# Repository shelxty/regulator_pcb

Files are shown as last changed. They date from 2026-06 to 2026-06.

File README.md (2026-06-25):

# 5V to 3.3V TPS79333 Regulator Board



After a lot of struggle with attempting to understand KiCad (thank you Hack Club Fallout mentors!) I made a simple linear voltage regulator to get started with learning, since this was a project simple enough to actually understand completely (schematic, PCB, everything). It's the first PCB I fully finished, designed in KiCad. I guess it can also be counted as my first actual electronics project! 

This is a tiny breakout board that takes unregulated input voltage (anywhere between around 3.4V to 5V) and outputs clean, fixed 3.3V volts. 

## Custom Features
- **Two LEDs:** This board has a red LED that lights up when input power is applied, and a green LED that confirms the output rail is working and regulating the voltage.
- **Feed-forward capacitor (C3):** On the feedback path, a feed-forward capacitor is set to improve noise rejection.
- **Compactness:** Each part has a footprint of 0805 or smaller, meaning this regulator board is extremely tiny and portable.

...and a very bad drawing I impulsively drew.

## How the Circuit Works (w/ Labels)
| Label | Part | What it Does |
|---|---|---|
| U1 | TPS79333 | The actual regulator, which drops the input voltage to a fixed output of 3.3V | 
| J1 | 2-pin connector | The power input (it takes in unregulated voltage), with a ground pin | 
| J2 | 2-pin connector | The power output (outputs a regulated 3.3V), with a ground pin | 
| C2 | 2.2uF capacitor | Input decoupler (it smoothes out incoming supply before it gets to the regulator) | 
| C1 | 0.1uF capacitor | Output decoupler (keeps the 3.3V rail stable should turbulence arise) | 
| C3 | 0.01uF capacitor | Feed-forward capacitor (improves noise rejection, according to the TI reference design) | 
| R2 | 280Ω resistor | Causes a 1.9V drop (3.3V - 1.9V) / 5mA = 280Ω | 
| R1 | 649Ω resistor | Causes a 1.75V drop (5 - 1.75V) / 5mA = 650Ω | 
| D1 | Red LED | Lights up when input voltage is applied | 
| D2 | Green LED | Lights up when 3.3V voltage is successfully outputted | 

## PCB Design 
This small regulator board is a 2 layer PCB with 2 sets of connectors. 



_PCB Editor View_



_Schematic Editor View (w/ comments & text for beginners to understand because I'm a complete beginner)_

## Bill of Materials 

|Item	|Description|	Reference	|Qty	|MOQ|	Value|	Unit Price ($)|	Total Price ($)	|Footprint|	MPN	|URL|
|-----|-----|-----|-----|-----|-----|-----|-----|-----|-----|-----|
|Capacitor	|Output decoupler|	C1|	1|	25	|0.1uF|	0.0061|	0.15|	Capacitor_SMD:C_0805_2012Metric|	C0805B104K500NT	|[Link](https://www.lcsc.com/product-detail/C476766.html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)|
|Capacitor	|Input decoupler|	C2	|1|	10|	2.2uF|	0.024|	0.24|	Capacitor_SMD:C_0805_2012Metric|	CL21B225KAFNNNE|	[Link](https://www.lcsc.com/product-detail/C19110.html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)|
|Capacitor|	Feed-forward capacitor|	C3|	1|	50|	0.01uF|	0.0094|	0.47|	Capacitor_SMD:C_0805_2012Metric|	CL21B103KBANNNC|	[Link](https://www.lcsc.com/product-detail/C1710.html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) |
|Red & green LEDs|	Lights up upon input|	D1,D2|	1|	100|  LED-RED,LED-GREEN|	0.0143|	1.43|	LED_SMD:LED_0805_2012Metric	|	| [Link](https://www.aliexpress.us/item/3256812235321424.html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)|
| 2-pin connector|	Power input/output	|J1,J2|	2|	10|	Conn_01x02|	0.0191	|1.91|	Connector_PinHeader_2.54mm:PinHeader_1x02_P2.54mm_Vertical|	|	[Link](https://www.aliexpress.us/item/3256807253955994.html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) | 
|Resistor|	649 Ohms|	R1|	1|100|		649|	0.001|	0.1|	Resistor_SMD:R_0805_2012Metric|	HRC0805F6490FNTN|	[Link](https://www.lcsc.com/product-detail/C55098624.html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) | 
| Resistor|	280 Ohms|	R2|	1|	100|	280|	0.0031|	0.31|	Resistor_SMD:R_0805_2012Metric|	FRC0805F2800TS|	[Link](https://www.lcsc.com/product-detail/C2960739.html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) |
| TPS79333|	Regulator|	U1|	1|	5|	TPS79333-EP	|0.3|	1.52|	Package_TO_SOT_SMD:SOT-23-5|	TPS79333DBVR|	[Link](https://www.lcsc.com/product-detail/C9840.html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) | 
| PCB Fabrication | Producing PCB from JLCPCB | |  1 | | | 2.2 | 2.2 | | | |
| PCB Fabrication | Producing PCB from JLCPCB | |  1 | | | 3.12 | 3.12 | | | |
| **Total**|  |  | 			**11**	|  |  |  |			**11.45**  | 

----

TPS79333 Regulator Board

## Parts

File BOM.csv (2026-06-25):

Item | Description | Reference | Qty | MOQ | Value | Unit Price ($) | Total Price ($) | Footprint | MPN | URL
Capacitor | Output decoupler | C1 | 1 | 25 | 0.1uF | 0.0061 | 0.15 | Capacitor_SMD:C_0805_2012Metric | C0805B104K500NT | https://www.lcsc.com/product-detail/C476766.html
Capacitor | Input decoupler | C2 | 1 | 10 | 2.2uF | 0.024 | 0.24 | Capacitor_SMD:C_0805_2012Metric | CL21B225KAFNNNE | https://www.lcsc.com/product-detail/C19110.html
Capacitor | Feed-forward capacitor | C3 | 1 | 50 | 0.01uF | 0.0094 | 0.47 | Capacitor_SMD:C_0805_2012Metric | CL21B103KBANNNC | https://www.lcsc.com/product-detail/C1710.html
Red & green LEDs | Lights up upon input | D1,D2 | 1 | 100 | LED-RED,LED-GREEN | 0.0143 | 1.43 | LED_SMD:LED_0805_2012Metric |  | https://www.aliexpress.us/item/3256812235321424.html?curPageLogUid=dpkon91Z9mo7
2-pin connector | Power input/output | J1,J2 | 2 | 10 | Conn_01x02 | 0.0191 | 1.91 | Connector_PinHeader_2.54mm:PinHeader_1x02_P2.54mm_Vertical |  | https://www.aliexpress.us/item/3256807253955994.html?curPageLogUid=T0dEK33dI0p0
Resistor | 649 Ohms | R1 | 1 | 100 | 649 | 0.001 | 0.1 | Resistor_SMD:R_0805_2012Metric | HRC0805F6490FNTN | https://www.lcsc.com/product-detail/C55098624.html?s_z=n_q_t_resistor
Resistor | 280 Ohms | R2 | 1 | 100 | 280 | 0.0031 | 0.31 | Resistor_SMD:R_0805_2012Metric | FRC0805F2800TS | https://www.lcsc.com/product-detail/C2960739.html?s_z=n_q_t_resistor
TPS79333 | Regulator | U1 | 1 | 5 | TPS79333-EP | 0.3 | 1.52 | Package_TO_SOT_SMD:SOT-23-5 | TPS79333DBVR | https://www.lcsc.com/product-detail/C9840.html?s_z=n_q_TPS79333
PCB Fabrication | Producing PCB from JLCPCB |  | 1 |  |  | 2.2 | 2.2
PCB Shipping | Shipping PCB from JLCPCB |  | 1 |  |  | 3.12 | 3.12
Total |  |  | 11 |  |  |  | 11.45

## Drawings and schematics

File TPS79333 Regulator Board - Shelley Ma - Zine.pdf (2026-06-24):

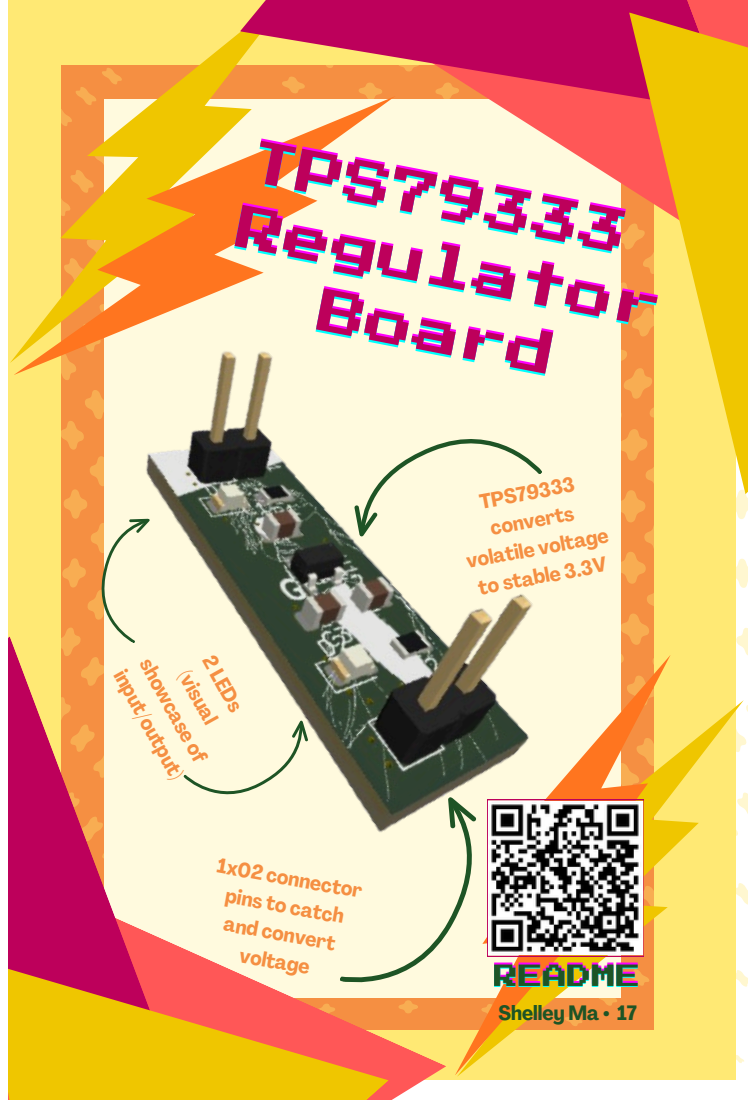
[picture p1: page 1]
TPS79333 TPS79333 R; S79333 ulator; Regulator; ulator ard; 2 LEDs (visual; showcase of input/output); TPS79333 converts volatile voltage to stable 3.3V; x02 connector; and convert voltage; RREEAADDMMEE; Shelley Ma • 17

ins to catch

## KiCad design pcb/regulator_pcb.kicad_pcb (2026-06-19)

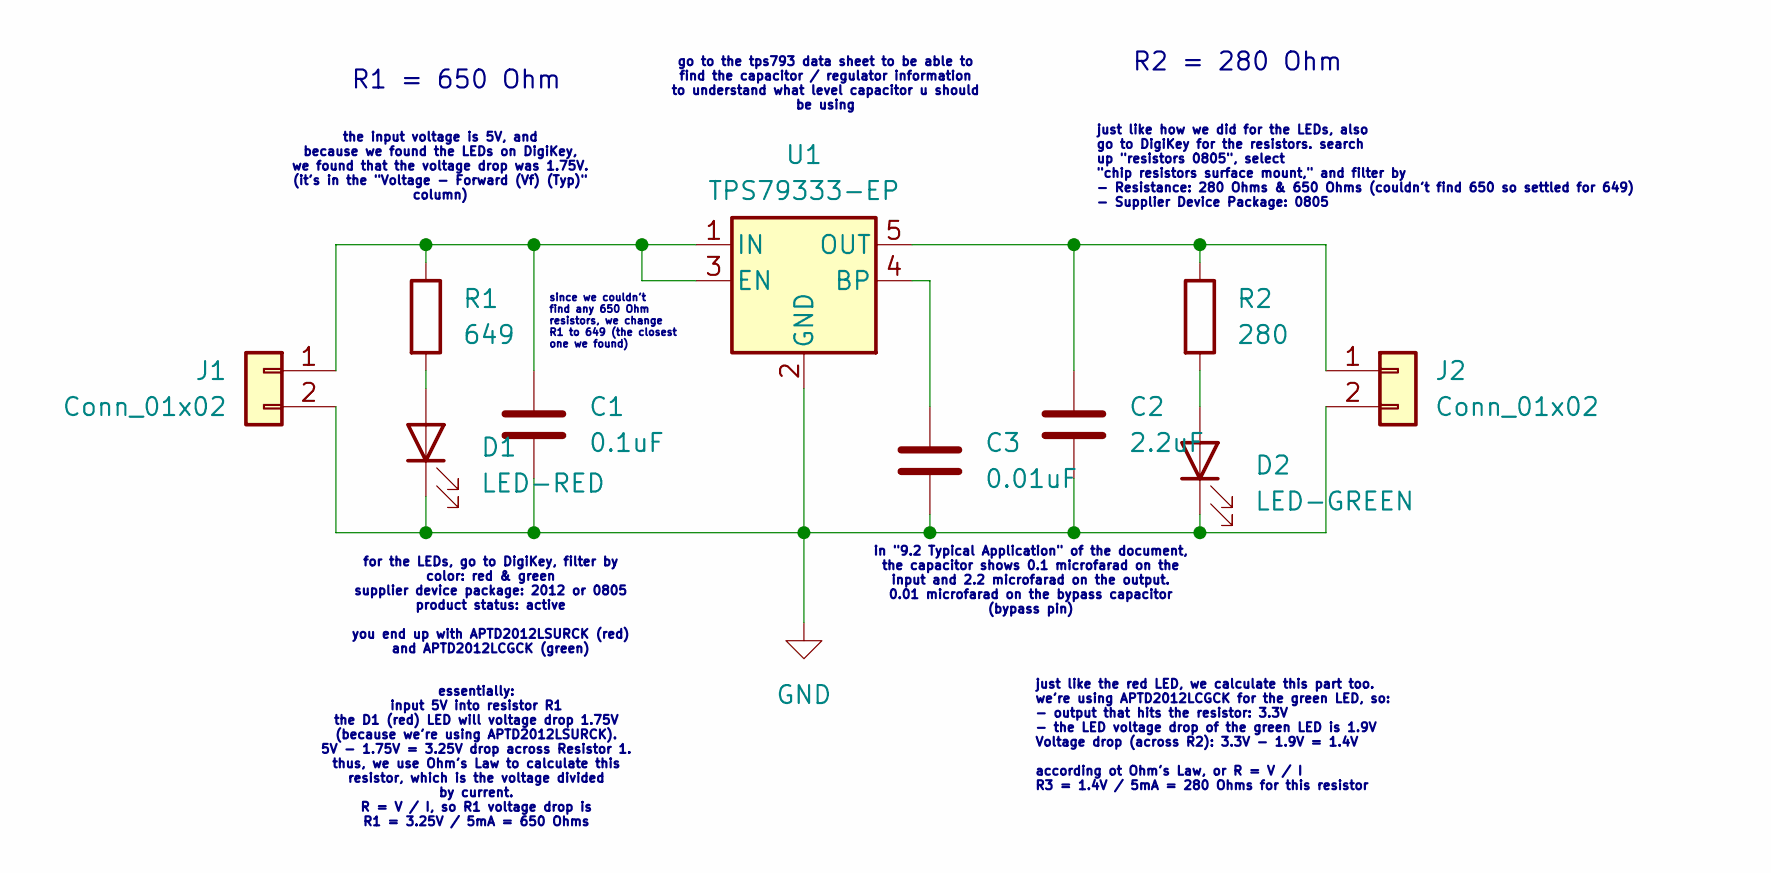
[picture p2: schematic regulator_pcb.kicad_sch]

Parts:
C1: 0.1uF; C_0805_2012Metric
C2: 2.2uF; C_0805_2012Metric
C3: 0.01uF; C_0805_2012Metric
D1: LED-RED; LED_0805_2012Metric
D2: LED-GREEN; LED_0805_2012Metric
J1, J2: Conn_01x02; PinHeader_1x02_P2.54mm_Vertical
R1: 649; R_0805_2012Metric
R2: 280; R_0805_2012Metric
U1: TPS79333-EP; SOT-23-5

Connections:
GND: C1.2, C2.2, C3.2, D1.1 (K), D2.1 (K), J1.2, J2.2, U1.2 (GND)
unnamed: D1.2 (A), R1.2
unnamed: D2.2 (A), R2.2
unnamed: C1.1, J1.1, R1.1, U1.1 (IN), U1.3 (EN)
unnamed: C2.1, J2.1, R2.1, U1.5 (OUT)
unnamed: C3.1, U1.4 (BP)

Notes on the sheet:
R2 = 280 Ohm
in "9.2 Typical Application" of the document, the capacitor shows 0.1 microfarad on the input and 2.2 microfarad on the output. 0.01 microfarad on the bypass capacitor (bypass pin)
just like how we did for the LEDs, also go to DigiKey for the resistors. search up "resistors 0805", select "chip resistors surface mount," and filter by - Resistance: 280 Ohms & 650 Ohms (couldn't find 650 so settled for 649) - Supplier Device Package: 0805
since we couldn't find any 650 Ohm resistors, we change R1 to 649 (the closest one we found)
go to the tps793 data sheet to be able to find the capacitor / regulator information to understand what level capacitor u should be using
for the LEDs, go to DigiKey, filter by color: red & green supplier device package: 2012 or 0805 product status: active you end up with APTD2012LSURCK (red) and APTD2012LCGCK (green)
essentially: input 5V into resistor R1 the D1 (red) LED will voltage drop 1.75V (because we're using APTD2012LSURCK). 5V - 1.75V = 3.25V drop across Resistor 1. thus, we use Ohm's Law to calculate this resistor, which is the voltage divided by current. R = V / I, so R1 voltage drop is R1 = 3.25V / 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
R1 = 650 Ohm
just like the red LED, we calculate this part too. we're using APTD2012LCGCK for the green LED, so: - output that hits the resistor: 3.3V - the LED voltage drop of the green LED is 1.9V Voltage drop (across R2): 3.3V - 1.9V = 1.4V according ot Ohm's Law, or R = V / I R3 = 1.4V / 5mA = 280 Ohms for 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
the input voltage is 5V, and because we found the LEDs on DigiKey, we found that the voltage drop was 1.75V. (it's in the "Voltage - Forward (Vf) (Typ)" column)

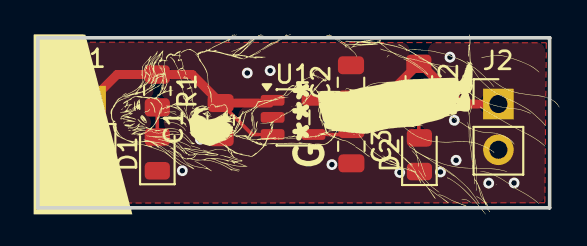
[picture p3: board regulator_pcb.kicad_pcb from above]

Board: 2 copper layers, 28.4 x 9.4 mm, 10 parts (0 on the bottom side), 6 nets.

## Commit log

2026-06-19 finished schematic, almost done with pcb
    [regulator_pcb.kicad_pcb, regulator_pcb.kicad_sch]
2026-06-19 finished copper fill and got everything drc-verified!
    [regulator_pcb.kicad_pcb]
2026-06-20 Update README with project details and features
    Added detailed project description, features, and circuit explanation.
2026-06-20 Add Bill of Materials section to README
2026-06-20 added bom
    [BOM_regulator_pcb.csv]
2026-06-24 moving files asdfasdf
    [regulator_pcb.kicad_sch]
2026-06-24 Update BOM.csv with new items and quantities
    [BOM.csv]
2026-06-24 Revise component table and include PCB fabrication costs
    Updated component list and added PCB fabrication details.
2026-06-25 gerbers
    gerb
2026-06-25 Adjust PCB fabrication cost and total in README
    Updated PCB fabrication costs in the bill of materials.
2026-06-25 Update BOM.csv with new item entries and totals
    [BOM.csv]
2026-06-25 Revise BOM with updated component details
    Updated BOM.csv to reflect new pricing and quantities for components.
    [BOM.csv]
